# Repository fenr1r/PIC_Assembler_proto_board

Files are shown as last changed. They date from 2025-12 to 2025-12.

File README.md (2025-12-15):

# PIC_Assembler_proto_board
A experimental board for the book "A First Course in the Microcontroller Programing with PICmicro"

### 概要

CQ出版社の「はじめてのPICアセンブラ入門」のための実験用ボード（本の中ではユニバーサル基板に組んでいる回路を、プリント基板にしたもの）

詳しくはブログをご覧ください :

https://vita-brevis.hatenablog.com/entry/2025/12/15/085609

秋月のBタイプ基板（95 x 72mm）サイズで、「B基板用アクリルパネル」に合うようにしました。

- DC入力は5V
- スイッチは秋月で販売している"2MS1-T1-B4-M7-Q-E-S"です
- ネジ・スペーサーはM3で、スペーサーは基板の下は高さ5mm、基板の上は高さ25mmを使いました

###### 本の回路図と違う点

- PICkit3用のコネクタの実装
    - ISPできるようにした
- 電源周り
    - スイッチなどを実装
- サーボモーター用電源、小型モーター用電源とPIC用電源を繋ぐジャンパを設置
   - サーボモーターくらいなら電源共用でも動きました

###### 未検証の点

- USB-Cコネクタ周り（給電用に設けたが、使わなかった）
- モータードライバー TA7291P 周り（小型モーターを手に入れる前に読んでしまったため、実装していない）

###### 設計ミス、工夫の足りなかった点

Githubでも書きましたが、少し設計ミスや、工夫の足りなかった点があります。
（いないと思いますけど）もし発注するのであれば、適宜直してください。

- UARTはRS-232出力となっているが、TTLレベルの出力も用意しておけばよかった（FTDIのUSB-UART変換で読めるから。わざわざUSB-RS232アダプタ持ち出さなくてもいい）
- ADC用のVRを半固定抵抗で実装したが、いちいちドライバーを用意して回すのは手間なので、可変抵抗にしておけばよかった
- LCDとC7が干渉する
   - C7を低背のものにすれば解消する
- PICkit3のピンヘッダとRS-232のコネクタも干渉するが、これはもう仕方ない
- SWの番号の違い（本だと回路図は1, 2だが、ソースコード上は0, 1である。正直私のせいではない…）
- PIC16F877Aをゼロプレッシャー実装する
   - 今の基板はISP書き込みを念頭に置いている。が、ライターを使うならゼロプレッシャーになると思う

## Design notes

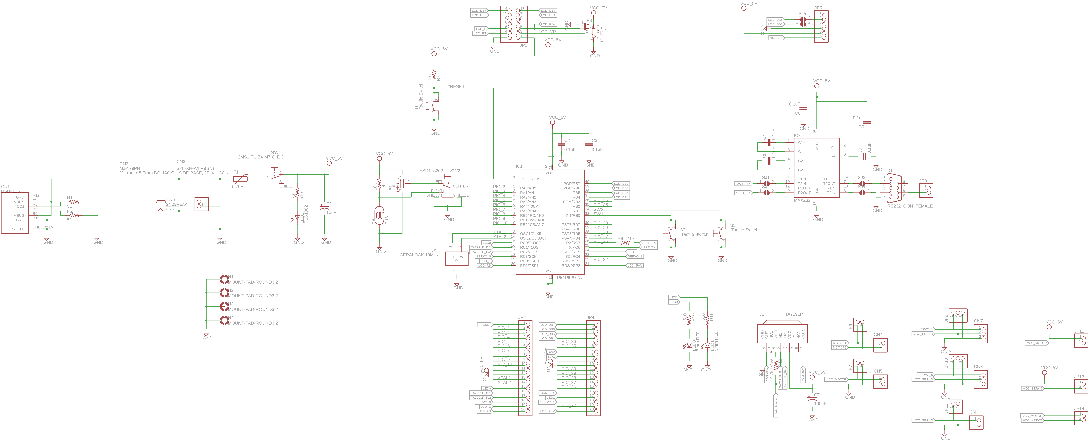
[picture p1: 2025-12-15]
sch.png

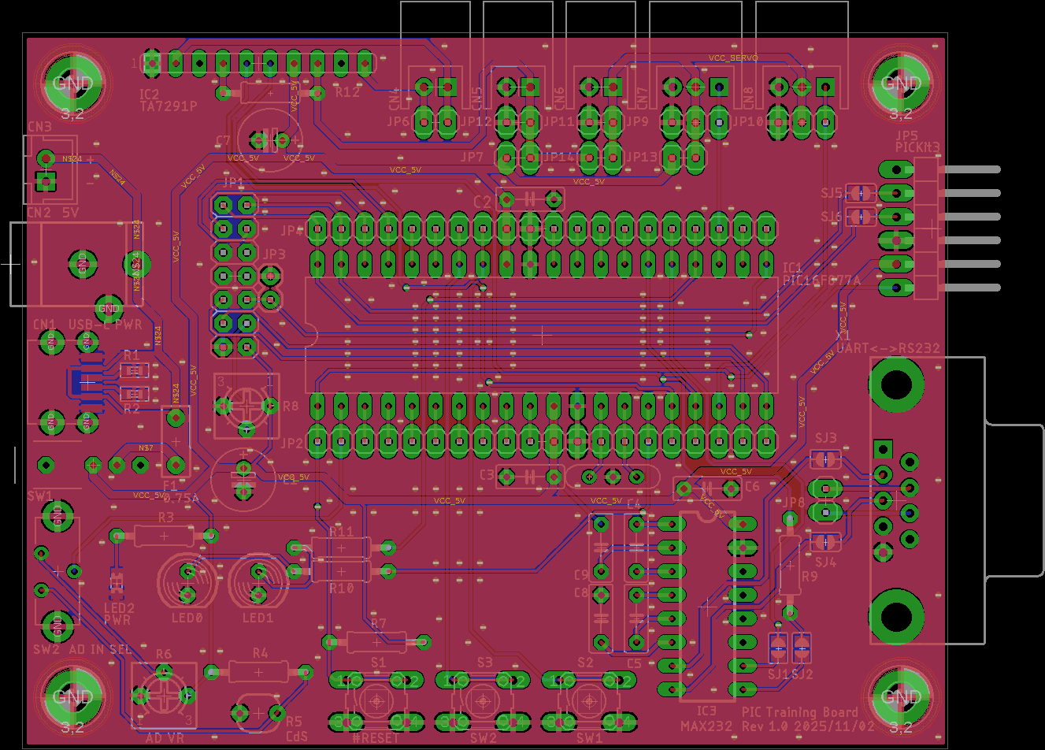
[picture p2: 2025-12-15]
brd.png

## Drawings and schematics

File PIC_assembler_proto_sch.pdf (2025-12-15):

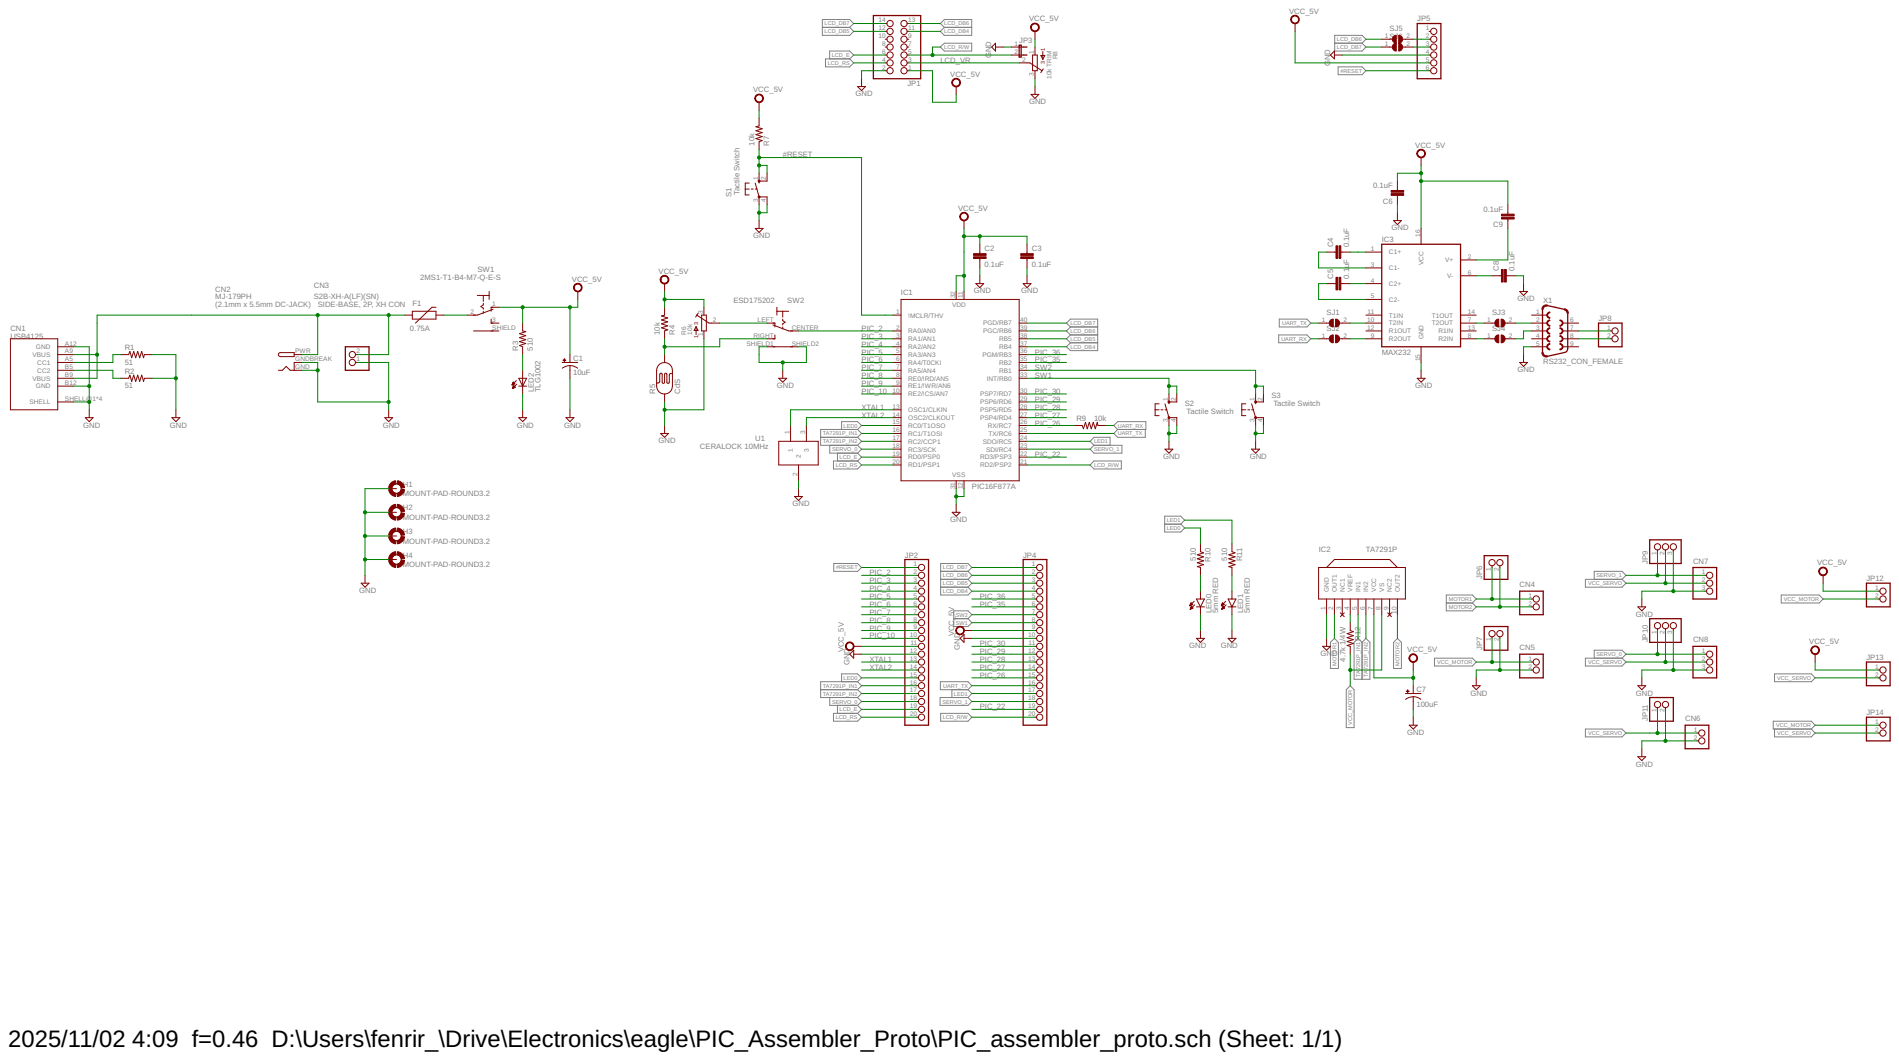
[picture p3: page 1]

(2.1mm x 5.5mm DC-JACK) SIDE-BASE, 2P, XH CON

MOUNT-PAD-ROUND3.2 MOUNT-PAD-ROUND3.2 MOUNT-PAD-ROUND3.2 MOUNT-PAD-ROUND3.2 GND

2025/11/02 4:09 f=0.46 D:\Users\fenrir_\Drive\Electronics\eagle\PIC_Assembler_Proto\PIC_assembler_proto.sch (Sheet: 1/1)

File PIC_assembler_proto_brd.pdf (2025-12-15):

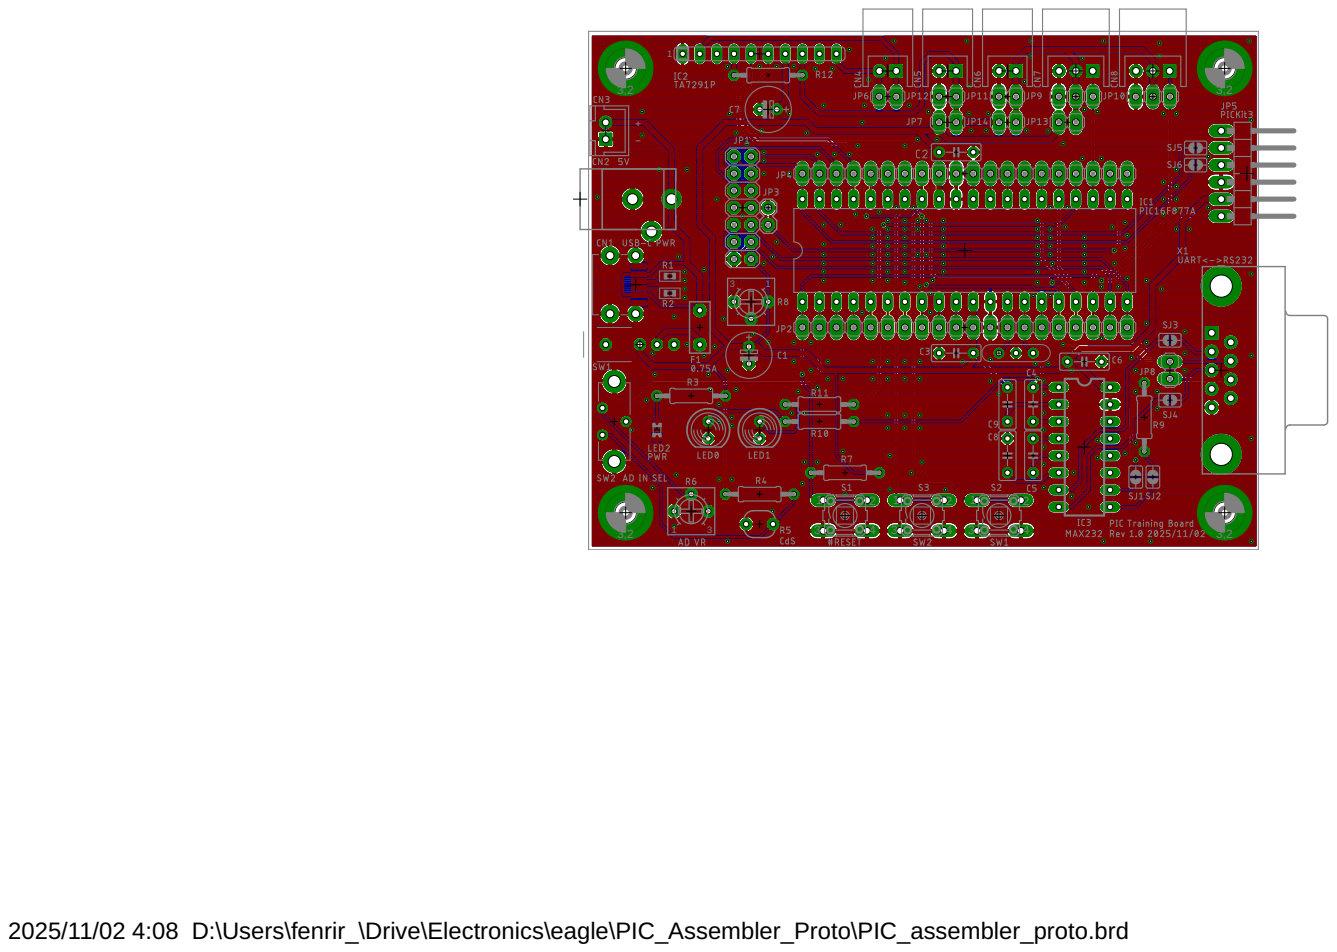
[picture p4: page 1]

2025/11/02 4:08 D:\Users\fenrir_\Drive\Electronics\eagle\PIC_Assembler_Proto\PIC_assembler_proto.brd

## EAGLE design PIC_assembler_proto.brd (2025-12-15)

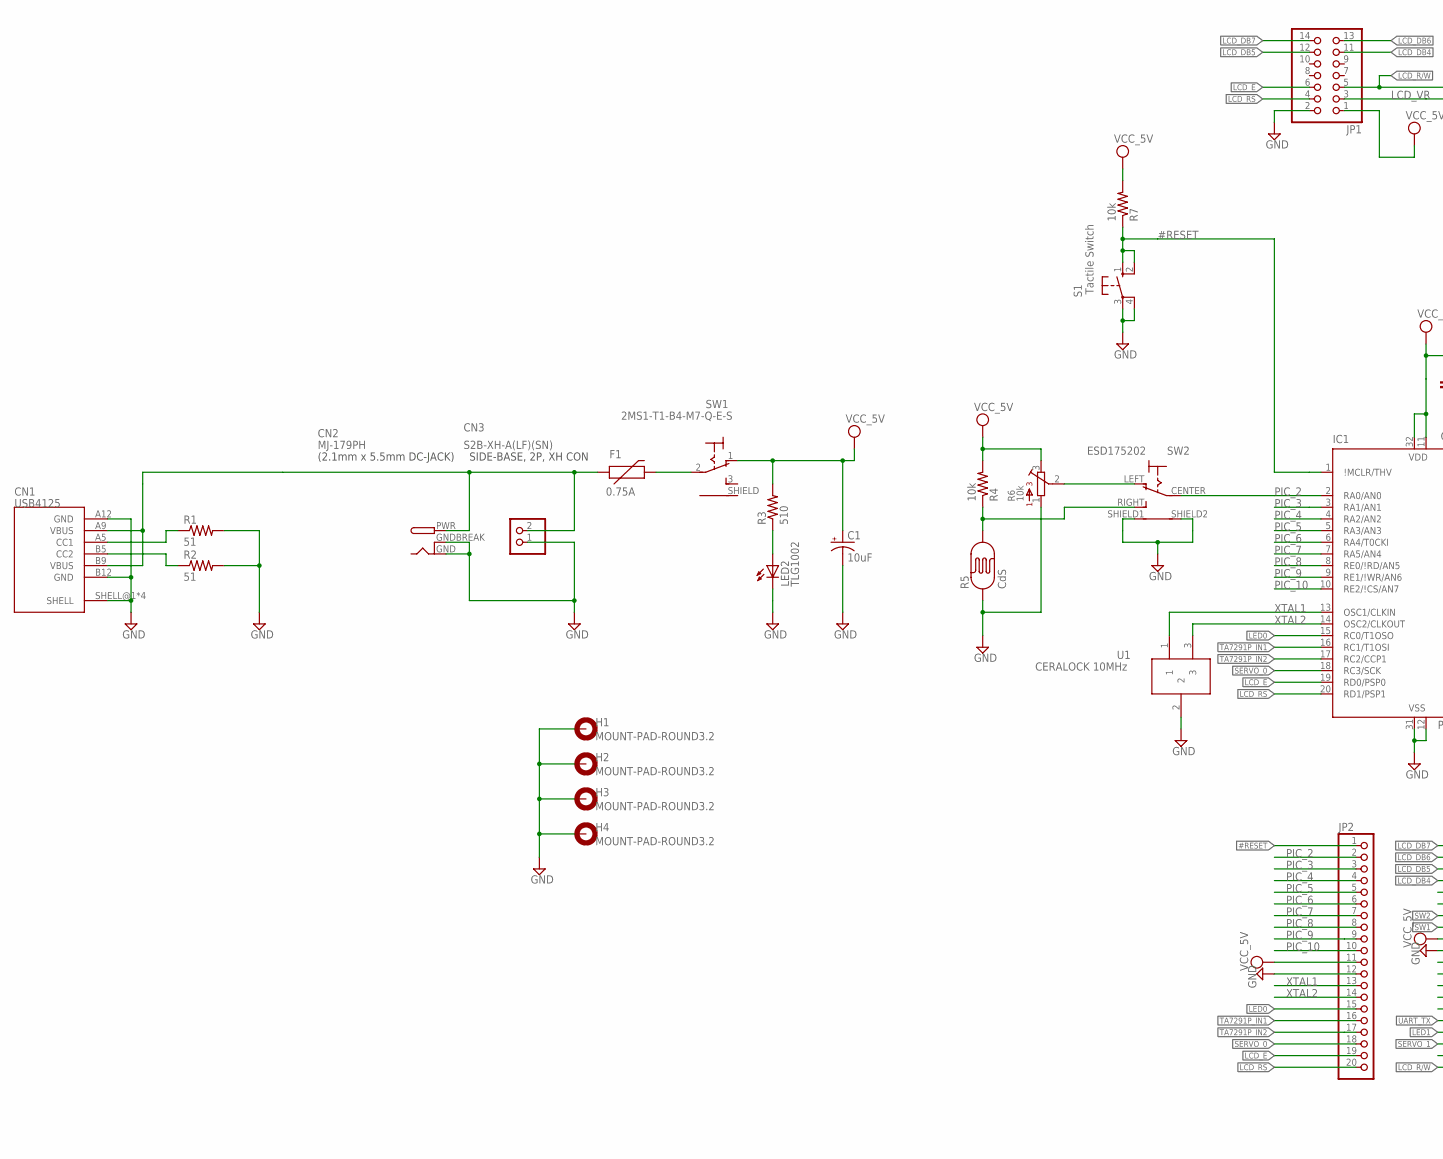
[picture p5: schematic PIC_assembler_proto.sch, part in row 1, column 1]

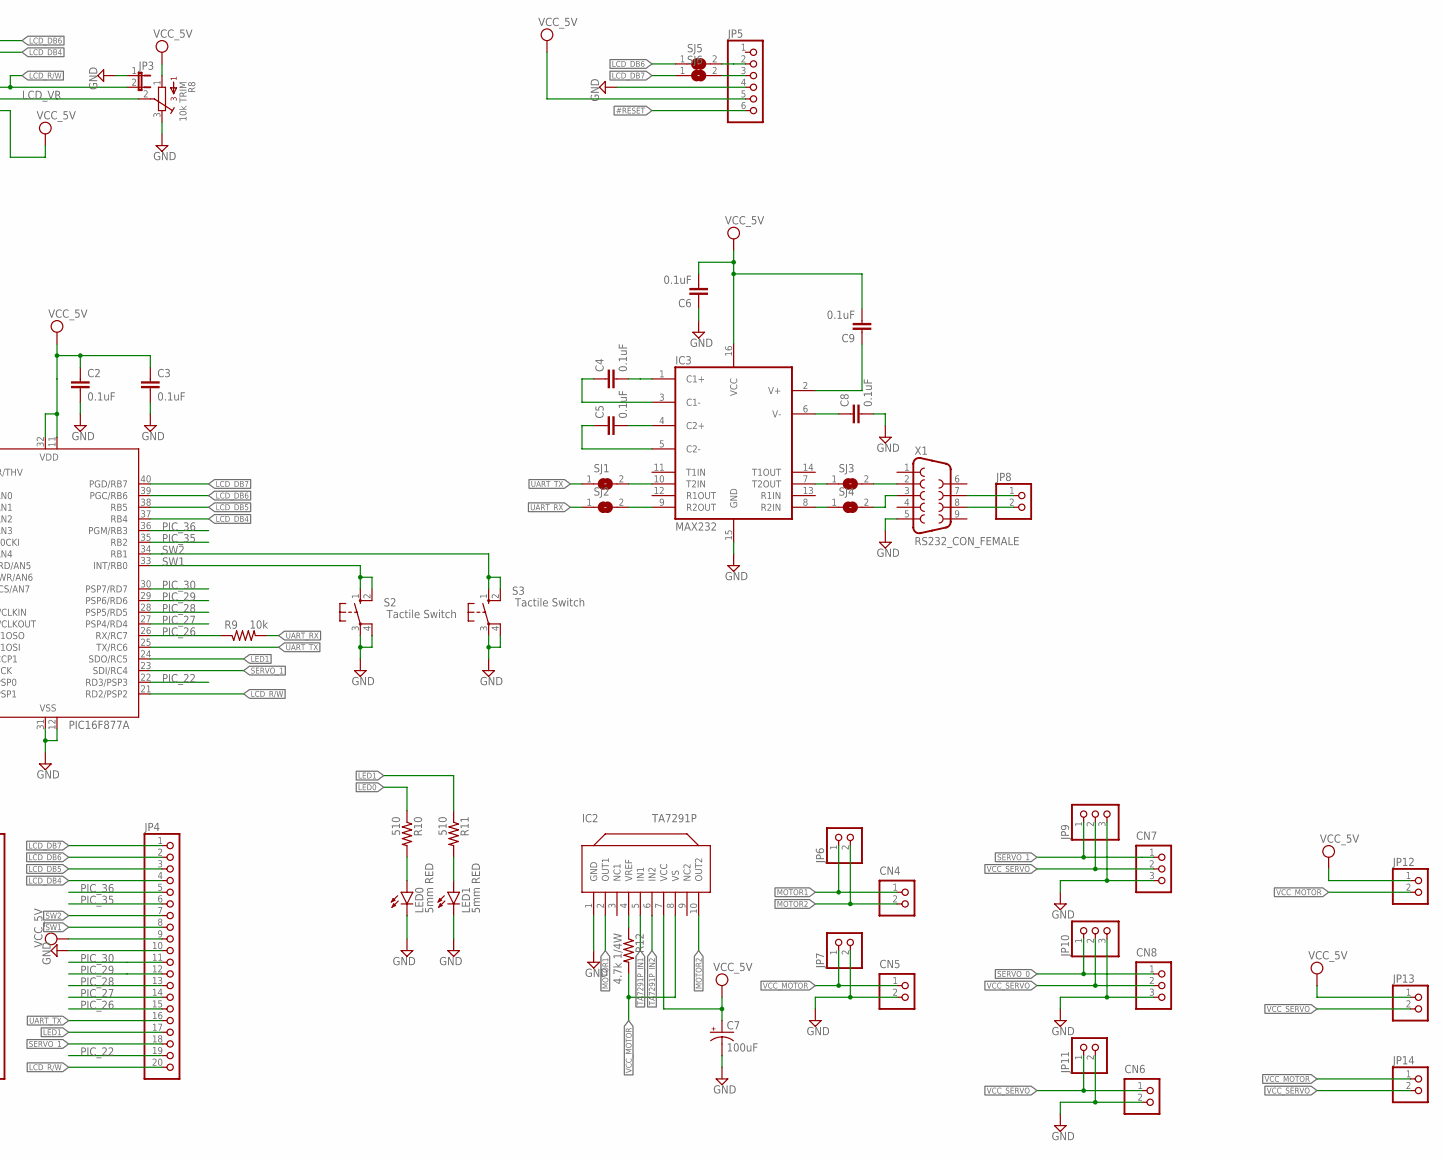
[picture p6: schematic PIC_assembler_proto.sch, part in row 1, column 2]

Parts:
C1: 10uF; E2,5-7
C2, C3, C4, C5, C6, C8, C9: 0.1uF; C050-025X075
C7: 100uF; E2,5-7
CN1: USB4125; USB4215
CN2: MJ-179PH; DCJACK_2MM_THIN_18742
CN3: S2B-XH-A(LF)(SN); B2B-XH-A
CN4, CN5, CN6: S2B-XH-A
CN7, CN8: S3B-XH-A
F1: 0.75A; PTC
H1, H2, H3, H4: MOUNT-PAD-ROUND3.2; 3,2-PAD
IC1: PIC16F877A; DIL40
IC2: TA7291P; SIL10
IC3: MAX232; DIL16
JP1: PINHD-2X7; 2X07
JP2, JP4: PINHD-1X20; 1X20
JP3: JUMPER-2PTH; 1X02
JP5: PINHD-1X6/90; 1X06/90
JP6, JP7, JP8, JP11, JP12, JP13, JP14: PINHD-1X2; 1X02
JP9, JP10: PINHD-1X3; 1X03
LED0, LED1: 5mm RED; LED5MM
LED2: TLG1002; CHIPLED_0805
R1, R2: 51; R0603
R3, R10, R11: 510; 0207/10
R4, R7, R9: 10k; 0207/10
R5: CdS; PHOTOCELL
R6: 10k; 3362P
R8: 10k TRIM; 3362P
R12: 4.7k 1/4W; 0207/10
S1, S2, S3: Tactile Switch; B3F-10XX
SJ1, SJ2, SJ3, SJ4, SJ5, SJ6: SJ
SW1: 2MS1-T1-B4-M7-Q-E-S
SW2: ESD175202
U1: CERALOCK 10MHz; CERALOCK
X1: RS232_CON_FEMALE; DB9

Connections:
#RESET: IC1.1 (\!MCLR/THV), JP2.1, JP5.6, R7.1, S1.1 (S), S1.2 (S1)
GND: C1.-, C2.2, C3.2, C6.1, C7.-, C8.2, CN1.A12 (GND), CN1.B12 (GND), CN1.SHELL@1 (SHELL), CN1.SHELL@2 (SHELL), CN1.SHELL@3 (SHELL), CN1.SHELL@4 (SHELL), CN2.GND, CN2.GNDBREAK, CN3.1, CN5.2, CN6.2, CN7.3, CN8.3, H1.B3,2, H2.B3,2, H3.B3,2, H4.B3,2, IC1.12 (VSS), IC1.31 (VSS), IC2.1 (GND), IC3.15 (GND), JP1.2, JP2.12, JP3.1, JP4.10, JP5.4, JP7.2, JP9.3, JP10.3, JP11.2, LED0.K (C), LED1.K (C), LED2.C, R1.2, R2.2, R5.1, R6.1, R8.3, S1.3, S1.4 (P1), S2.3, S2.4 (P1), S3.3, S3.4 (P1), SW2.SHIELD1, SW2.SHIELD2, U1.2, X1.5
LCD_DB4: IC1.37 (RB4), JP1.11, JP4.4
LCD_DB5: IC1.38 (RB5), JP1.12, JP4.3
LCD_DB6: IC1.39 (PGC/RB6), JP1.13, JP4.2, SJ5.1
LCD_DB7: IC1.40 (PGD/RB7), JP1.14, JP4.1, SJ6.1
LCD_E: IC1.19 (RD0/PSP0), JP1.6, JP2.19
LCD_R/W: IC1.21 (RD2/PSP2), JP1.5, JP3.2, JP4.20
LCD_RS: IC1.20 (RD1/PSP1), JP1.4, JP2.20
LCD_VR: JP1.3, R8.2
LED0: IC1.15 (RC0/T1OSO), JP2.15, R10.1
LED1: IC1.24 (SDO/RC5), JP4.17, R11.1
MOTOR1: CN4.1, IC2.2 (OUT1), JP6.1
MOTOR2: CN4.2, IC2.10 (OUT2), JP6.2
unnamed: JP8.1, X1.7
unnamed: SJ3.2, X1.2
unnamed: IC3.9 (R2OUT), SJ2.2
unnamed: R4.1, R5.2, SW2.RIGHT (O2)
unnamed: R6.2, SW2.LEFT (O1)
unnamed: IC3.8 (R2IN), SJ4.1
unnamed: F1.P$2 (2), SW1.2 (2COMM)
unnamed: IC3.10 (T2IN), SJ1.2
unnamed: JP8.2, X1.8
unnamed: IC2.4 (VREF), R12.1
unnamed: JP5.2, SJ5.2
unnamed: IC3.7 (T2OUT), SJ3.1
unnamed: JP5.3, SJ6.2
unnamed: SJ4.2, X1.3
unnamed: LED0.A, R10.2
unnamed: LED1.A, R11.2
unnamed: C9.1, IC3.2 (V+)
unnamed: C8.1, IC3.6 (V-)
unnamed: C5.2, IC3.4 (C2+)
unnamed: C5.1, IC3.5 (C2-)
unnamed: C4.1, IC3.3 (C1-)
unnamed: C4.2, IC3.1 (C1+)
unnamed: CN1.A9 (VBUS), CN1.B9 (VBUS), CN2.PWR, CN3.2, F1.P$1 (1)
unnamed: LED2.A, R3.1
unnamed: CN1.B5 (CC2), R2.1
unnamed: CN1.A5 (CC1), R1.1
PIC_2: IC1.2 (RA0/AN0), JP2.2, SW2.CENTER (COMMON)
PIC_3: IC1.3 (RA1/AN1), JP2.3
PIC_4: IC1.4 (RA2/AN2), JP2.4
PIC_5: IC1.5 (RA3/AN3), JP2.5
PIC_6: IC1.6 (RA4/T0CKI), JP2.6
PIC_7: IC1.7 (RA5/AN4), JP2.7
PIC_8: IC1.8 (RE0/\!RD/AN5), JP2.8
PIC_9: IC1.9 (RE1/\!WR/AN6), JP2.9
PIC_10: IC1.10 (RE2/\!CS/AN7), JP2.10
PIC_22: IC1.22 (RD3/PSP3), JP4.19
PIC_26: IC1.26 (RX/RC7), JP4.15, R9.1
PIC_27: IC1.27 (PSP4/RD4), JP4.14
PIC_28: IC1.28 (PSP5/RD5), JP4.13
PIC_29: IC1.29 (PSP6/RD6), JP4.12
PIC_30: IC1.30 (PSP7/RD7), JP4.11
PIC_35: IC1.35 (RB2), JP4.6
PIC_36: IC1.36 (PGM/RB3), JP4.5
SERVO_0: CN8.1, IC1.18 (RC3/SCK), JP2.18, JP10.1
SERVO_1: CN7.1, IC1.23 (SDI/RC4), JP4.18, JP9.1
SW1: IC1.33 (INT/RB0), JP4.8, S2.1 (S), S2.2 (S1)
SW2: IC1.34 (RB1), JP4.7, S3.1 (S), S3.2 (S1)
TA7291P_IN1: IC1.16 (RC1/T1OSI), IC2.5 (IN1), JP2.16
TA7291P_IN2: IC1.17 (RC2/CCP1), IC2.6 (IN2), JP2.17
UART_RX: R9.2, SJ2.1
UART_TX: IC1.25 (TX/RC6), JP4.16, SJ1.1
VCC_5V: C1.+, C2.1, C3.1, C6.2, C7.+, C9.2, IC1.11 (VDD), IC1.32 (VDD), IC2.7 (VCC), IC3.16 (VCC), JP1.1, JP2.11, JP4.9, JP5.5, JP12.1, JP13.1, R3.2, R4.2, R6.3, R7.2, R8.1, SW1.1
VCC_MOTOR: CN5.1, IC2.8 (VS), JP7.1, JP12.2, JP14.1, R12.2
VCC_SERVO: CN6.1, CN7.2, CN8.2, JP9.2, JP10.2, JP11.1, JP13.2, JP14.2
XTAL1: IC1.13 (OSC1/CLKIN), JP2.13, U1.1
XTAL2: IC1.14 (OSC2/CLKOUT), JP2.14, U1.3

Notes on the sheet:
(2.1mm x 5.5mm DC-JACK)
SIDE-BASE, 2P, XH CON

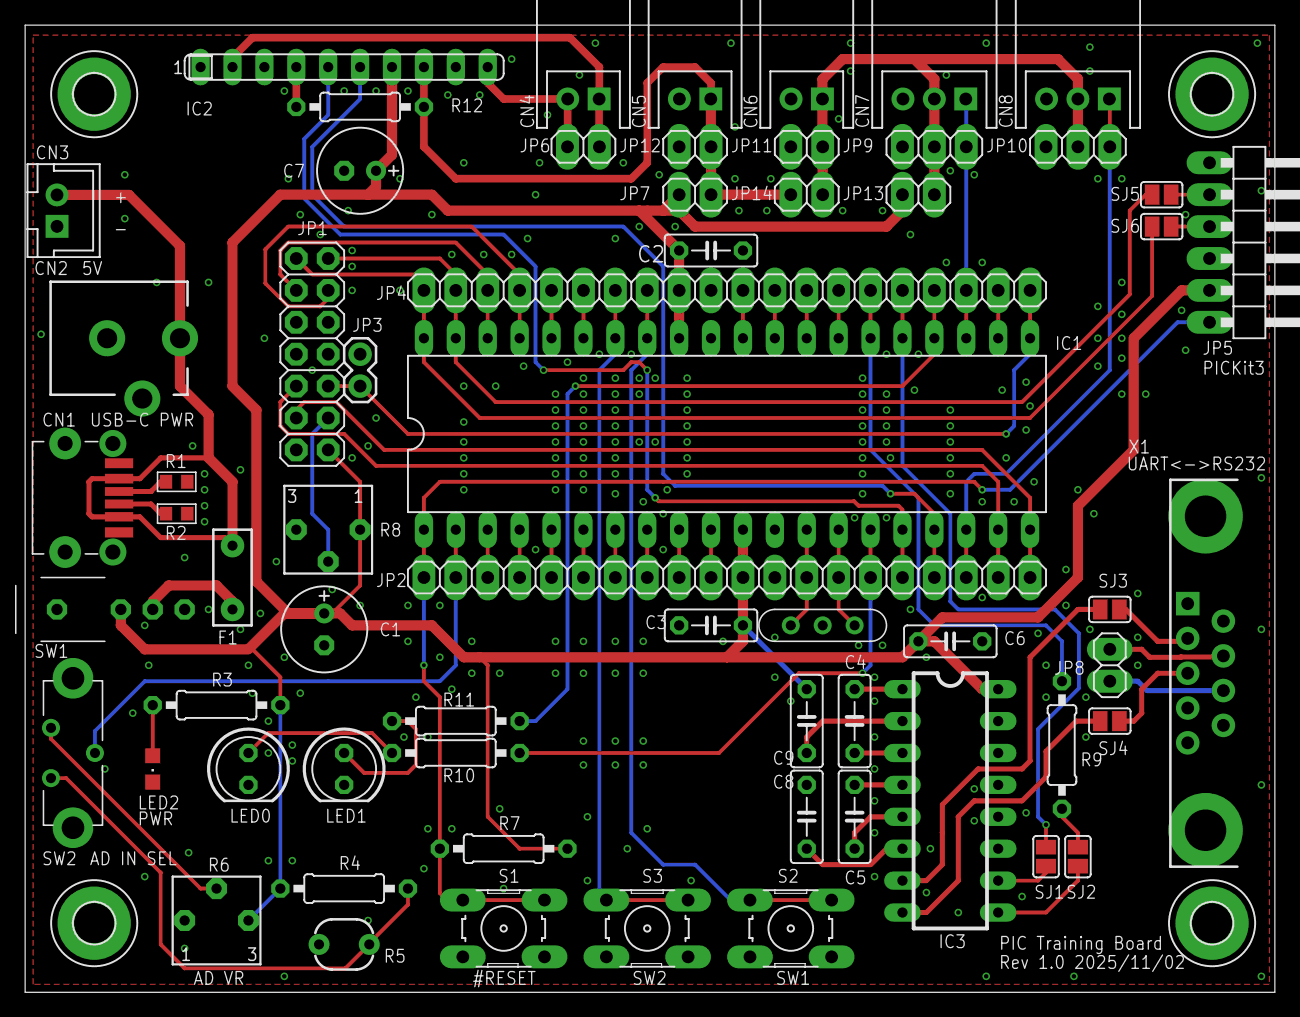
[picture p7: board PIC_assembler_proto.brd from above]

Board: 2 copper layers, 99.5 x 77.0 mm, 67 parts (0 on the bottom side), 70 nets.

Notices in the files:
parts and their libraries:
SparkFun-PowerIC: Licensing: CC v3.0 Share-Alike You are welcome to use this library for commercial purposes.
